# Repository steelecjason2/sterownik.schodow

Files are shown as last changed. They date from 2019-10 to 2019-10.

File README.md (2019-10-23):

16 stairs LED controller, and it's easy to extend by connecting just few wires to next TLC5940 PWM LED driver. 

parts not listed in schematics:

2x E18-D80NK Sensor Proximity 3-80cm,

2x microswitches, normal open.

SANPU 12VDC Waterproof LED Power Supply 12V DC 120W 10A IP67

Bluetooth HC-05

LED Strip 12V

PGM5516 photoresistor

2x potentiometer 10k multi-turn type 3/8''

https://www.youtube.com/watch?v=NjSVoOenioQ

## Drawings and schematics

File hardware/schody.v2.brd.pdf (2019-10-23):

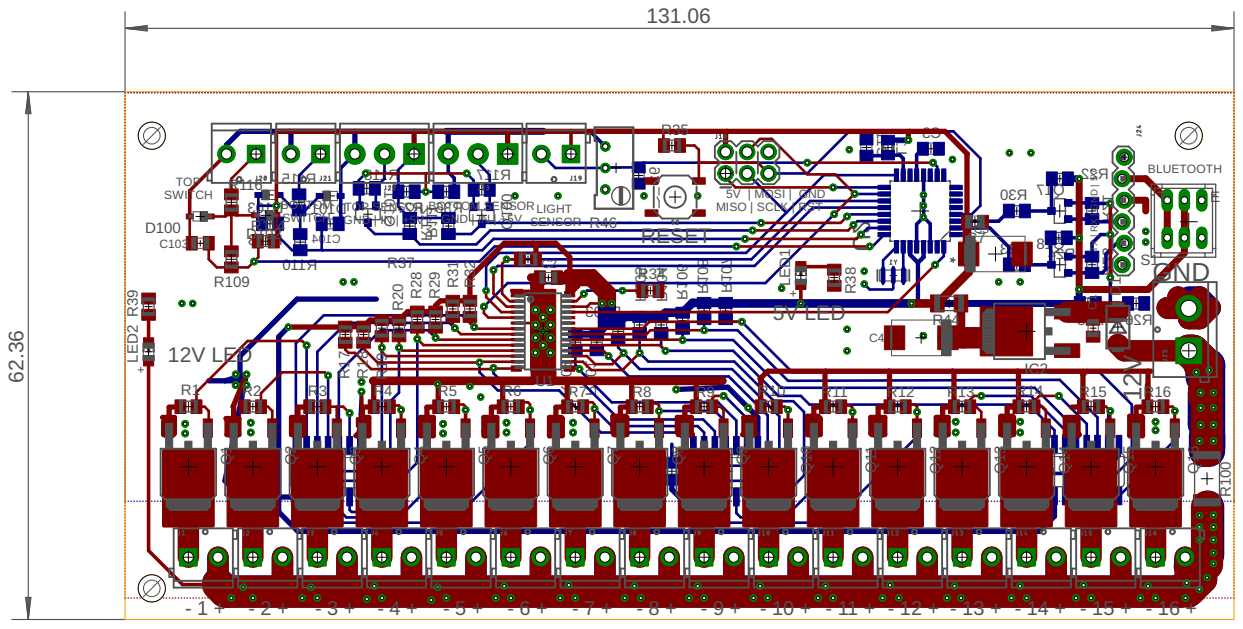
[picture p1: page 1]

TOP SENSOR GND | IN | +5V

5V | MOSI | GND MISO | SCLK | RST

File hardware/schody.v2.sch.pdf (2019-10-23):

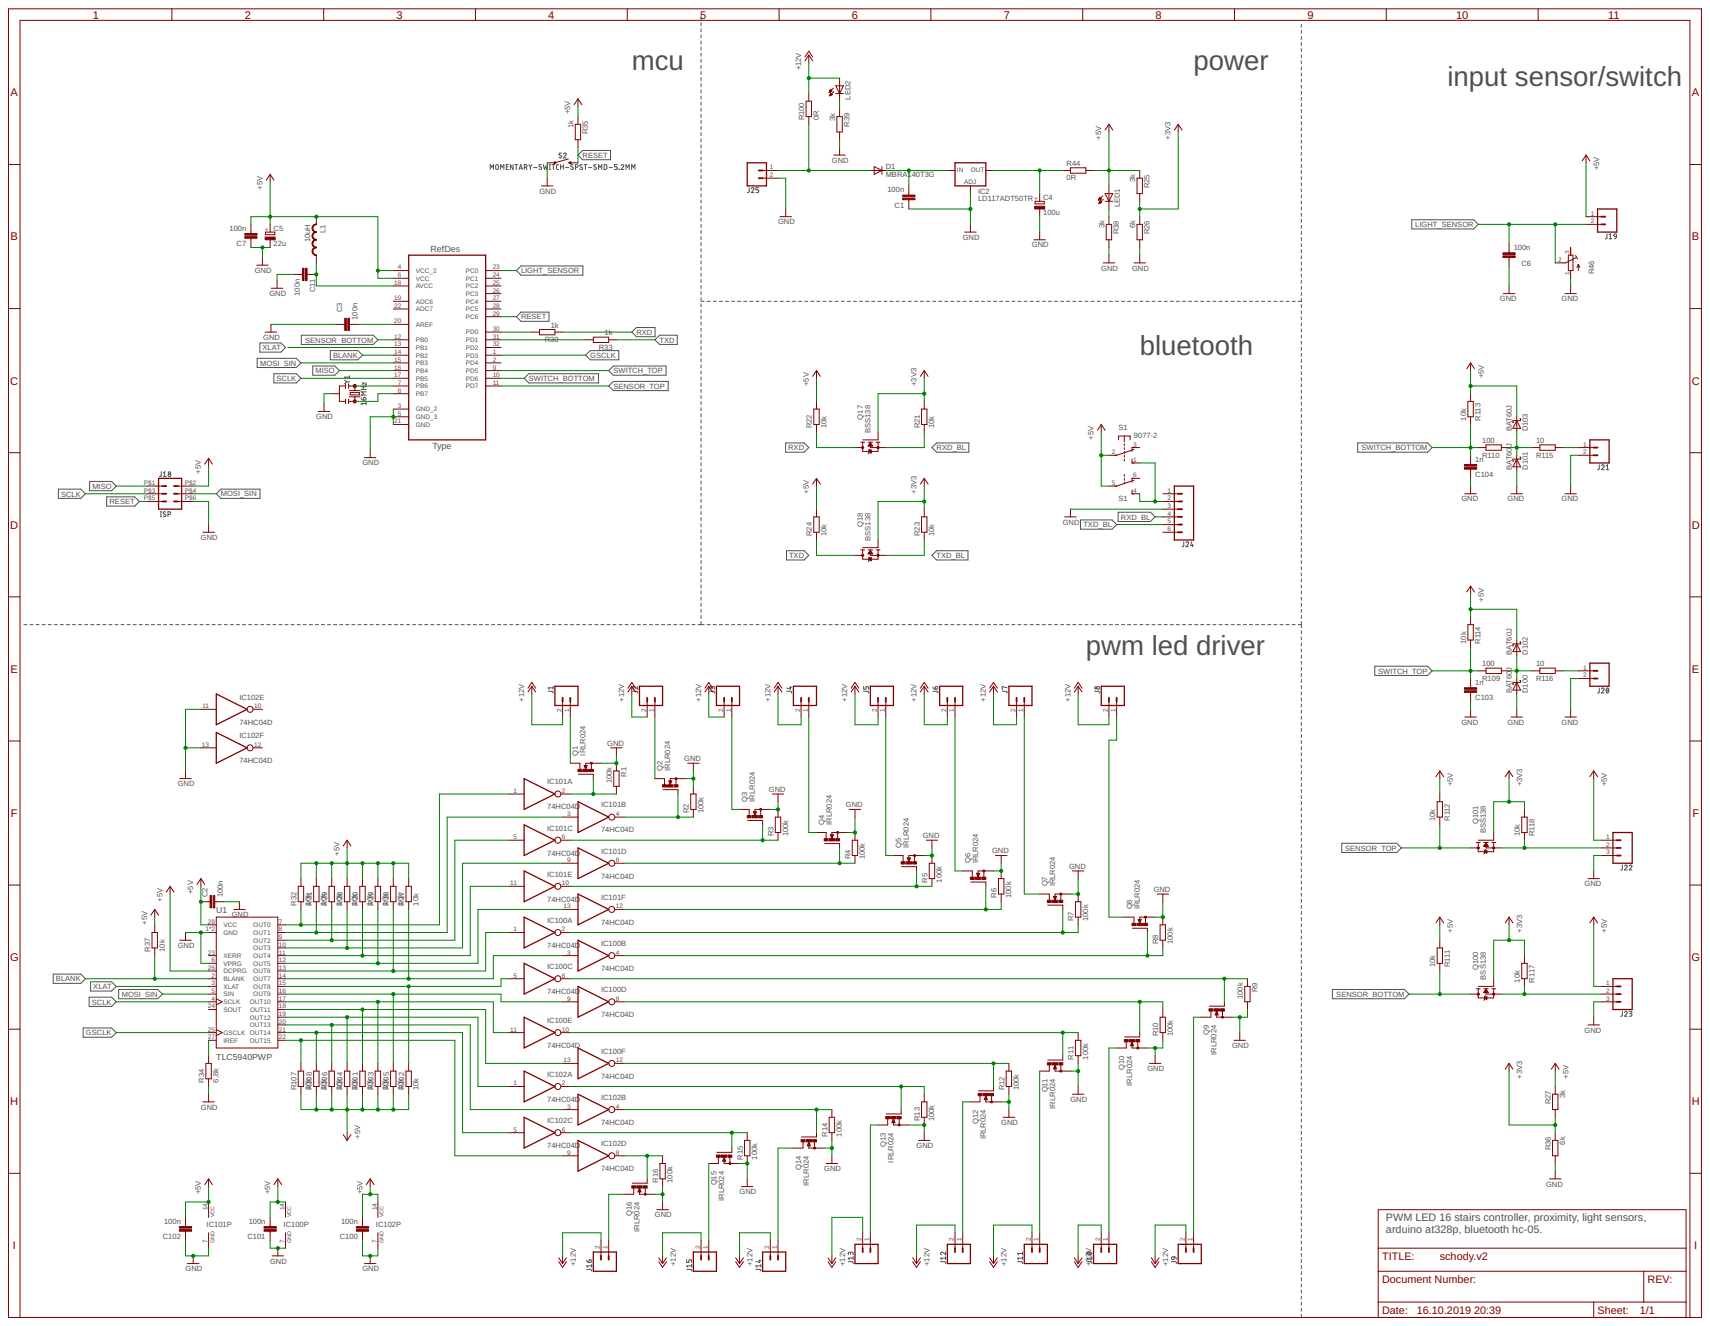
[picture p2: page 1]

PWM LED 16 stairs controller, proximity, light sensors, arduino at328p, bluetooth hc-05.

Document Number: | REV:

Date: 16.10.2019 20:39 | Sheet: 1/1

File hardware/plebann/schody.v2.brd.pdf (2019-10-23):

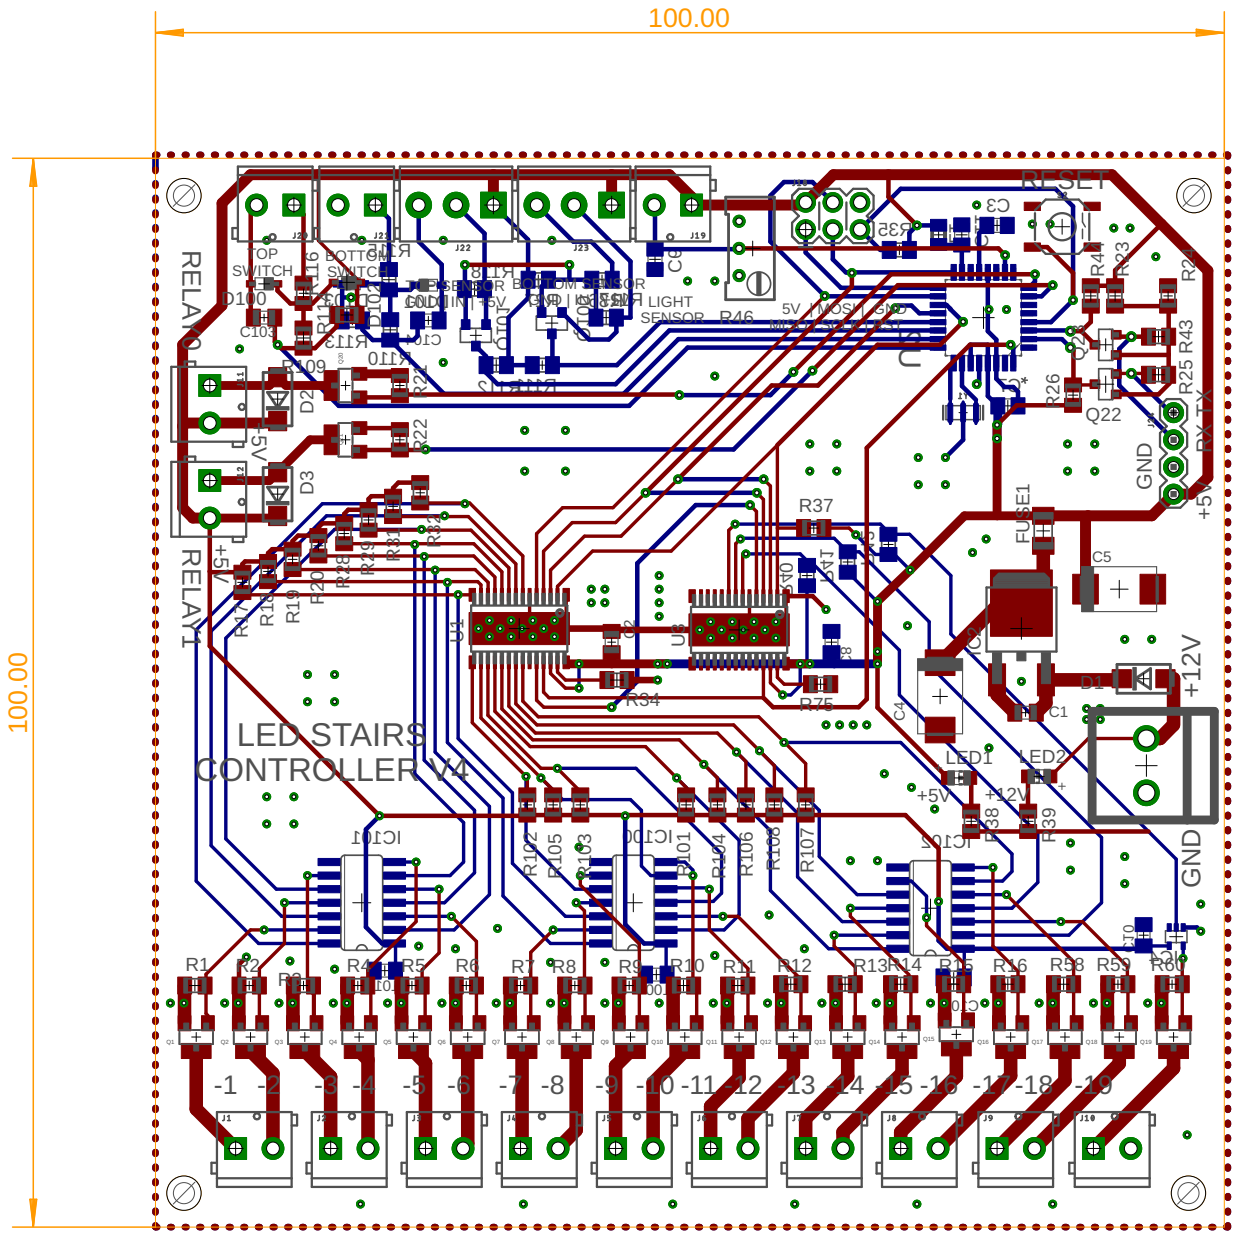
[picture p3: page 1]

BOTTOM SENSOR GND | IN | +5V

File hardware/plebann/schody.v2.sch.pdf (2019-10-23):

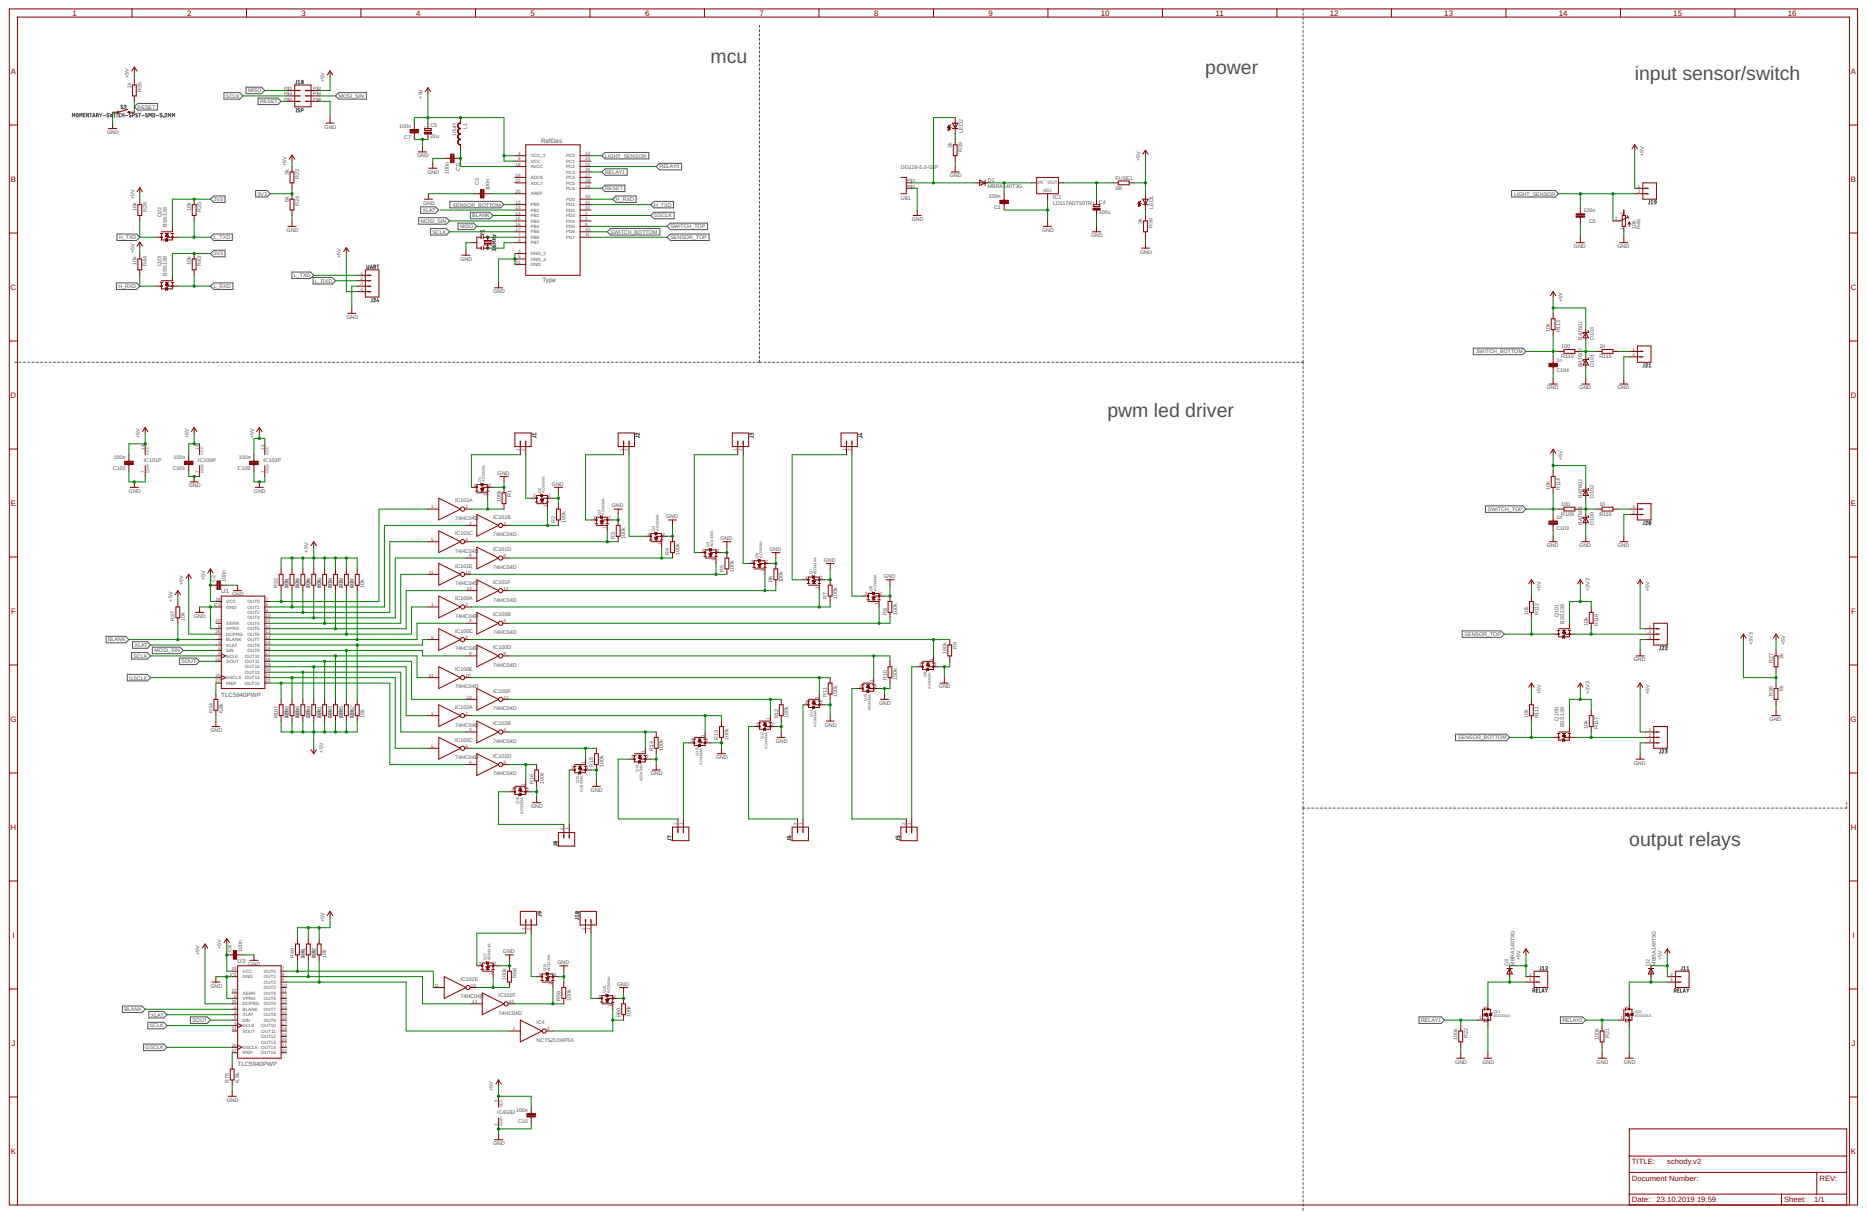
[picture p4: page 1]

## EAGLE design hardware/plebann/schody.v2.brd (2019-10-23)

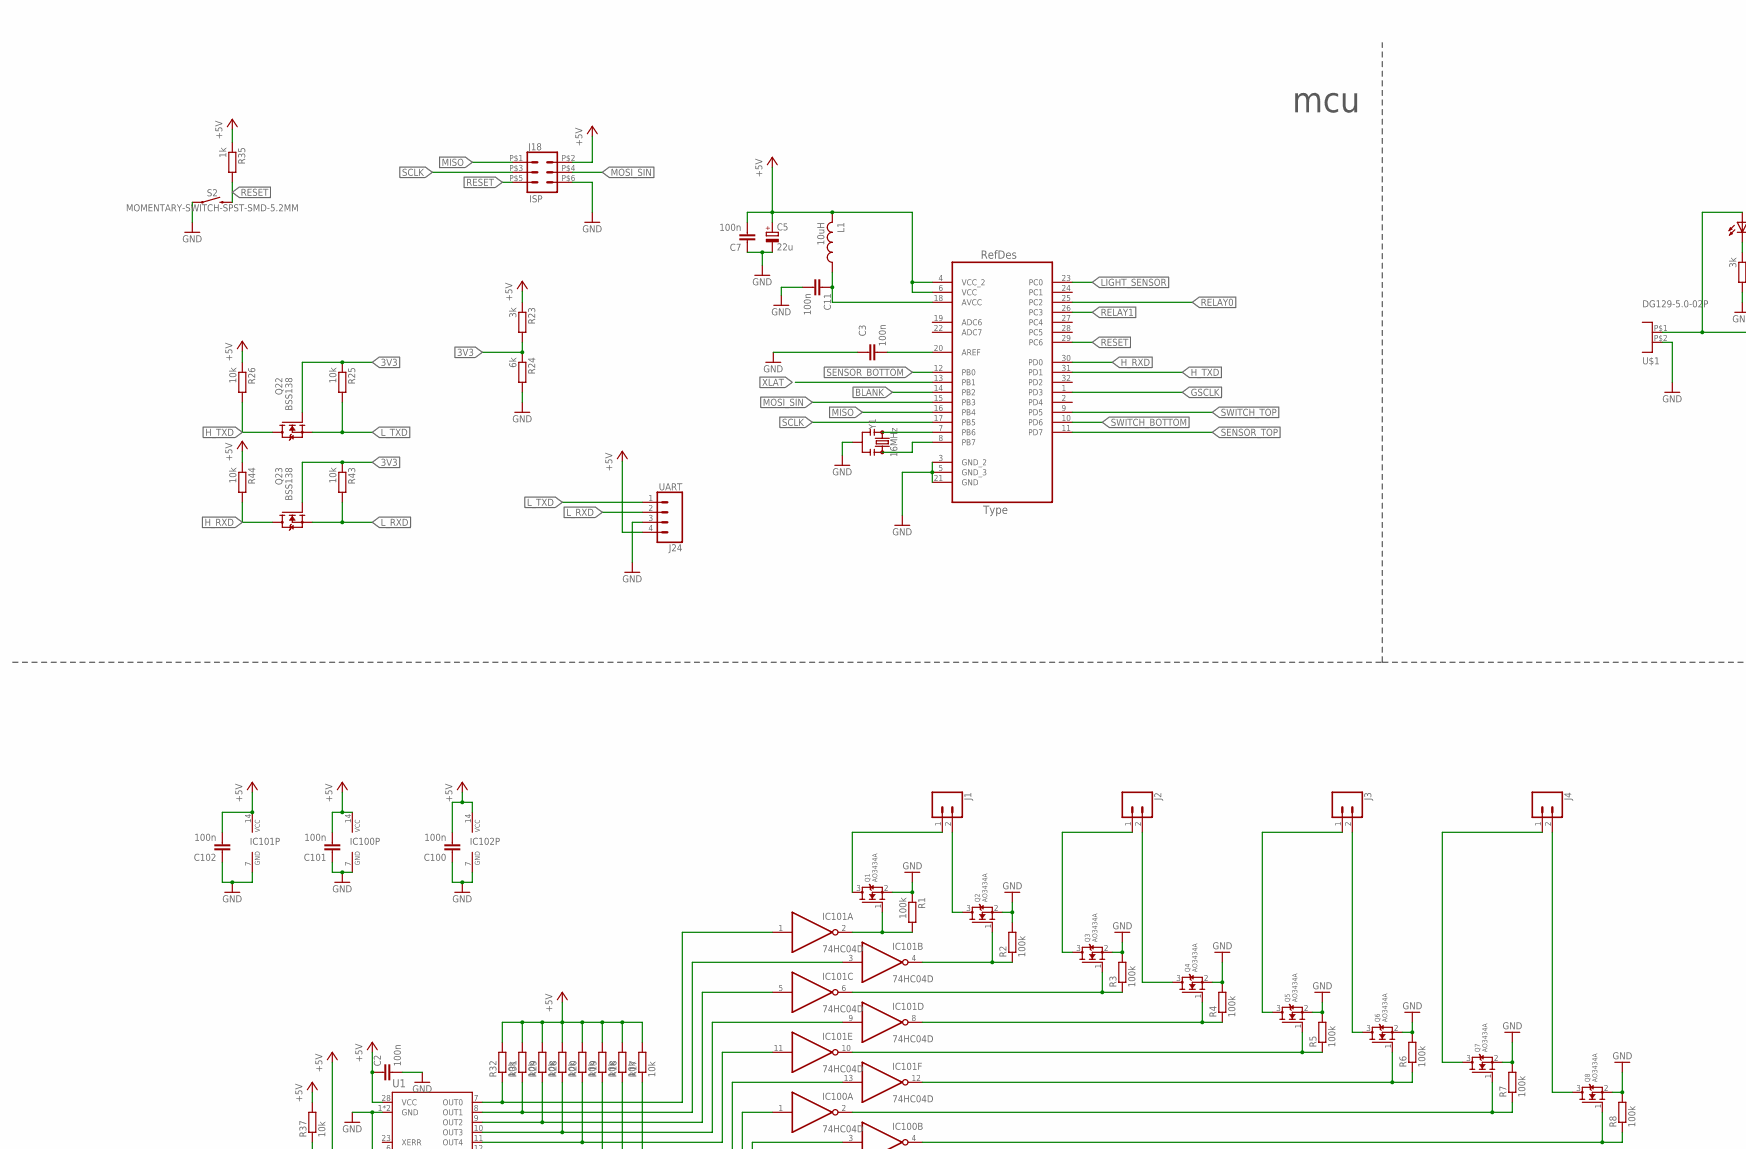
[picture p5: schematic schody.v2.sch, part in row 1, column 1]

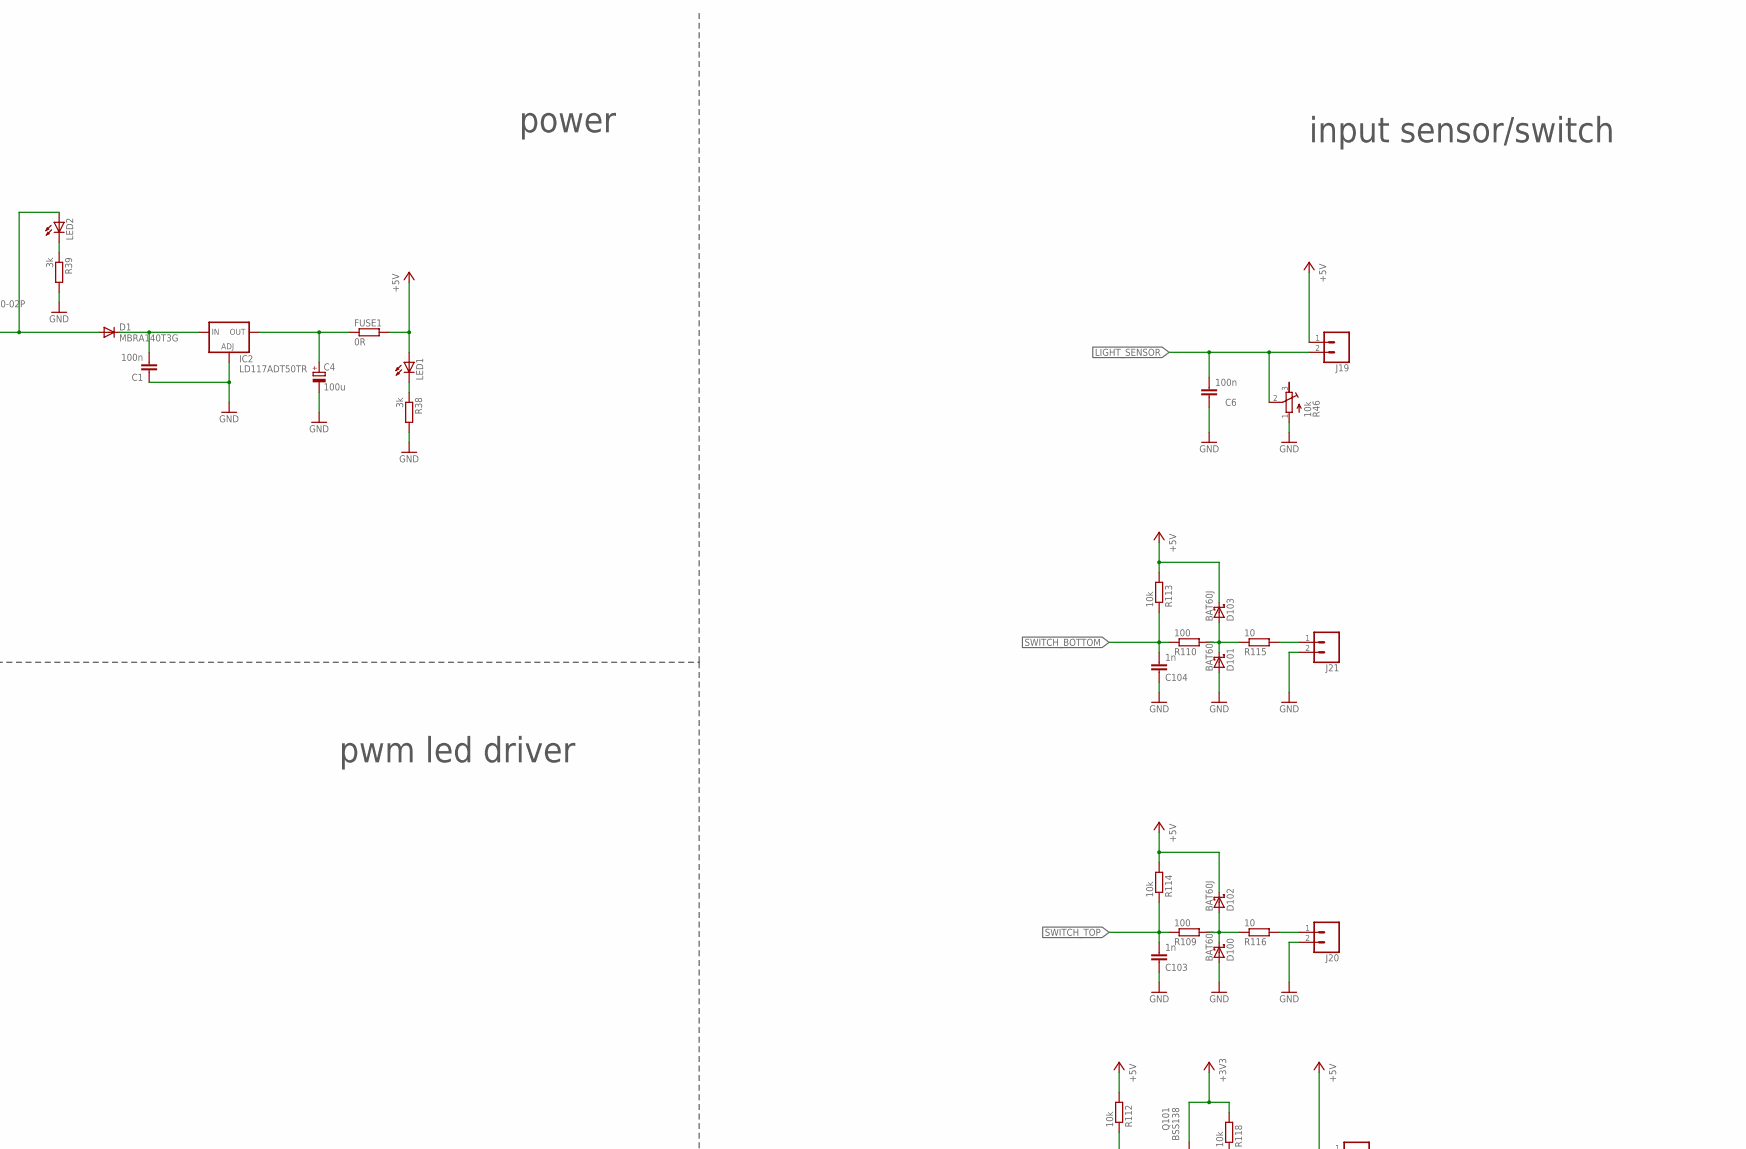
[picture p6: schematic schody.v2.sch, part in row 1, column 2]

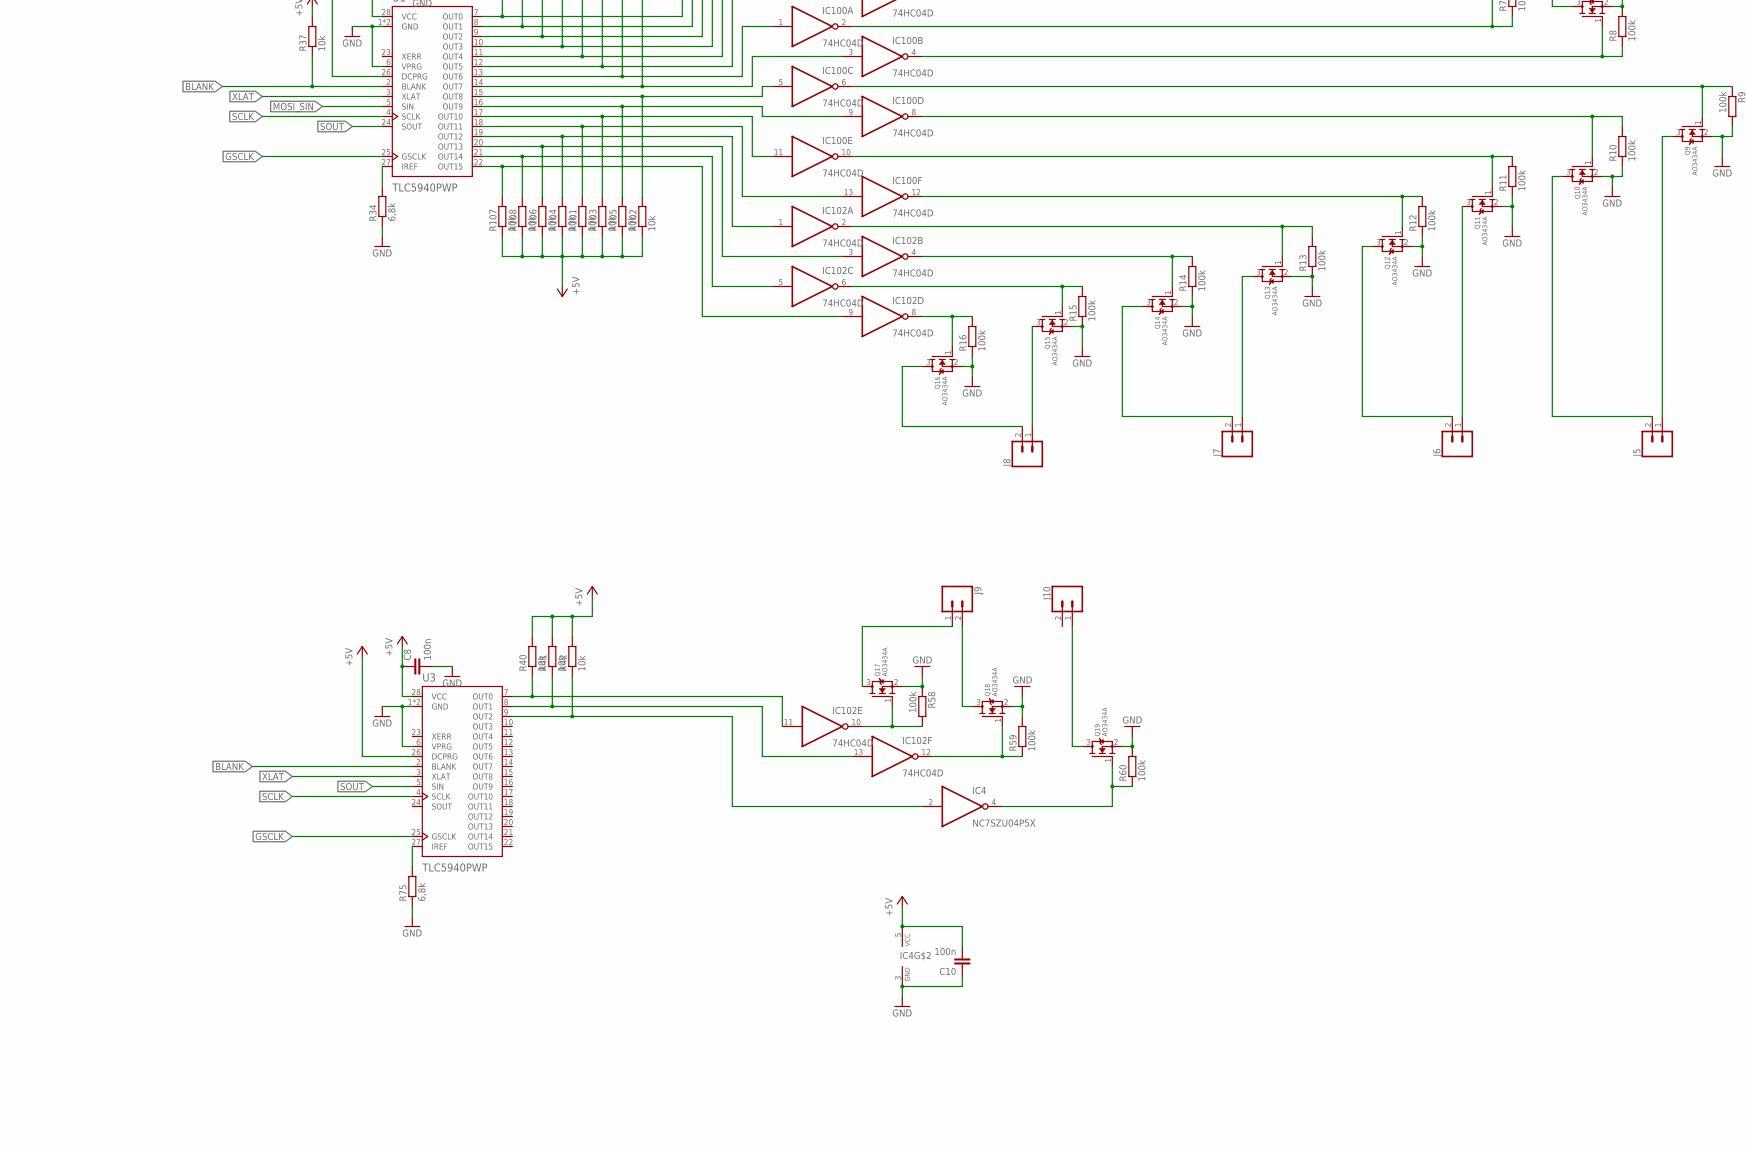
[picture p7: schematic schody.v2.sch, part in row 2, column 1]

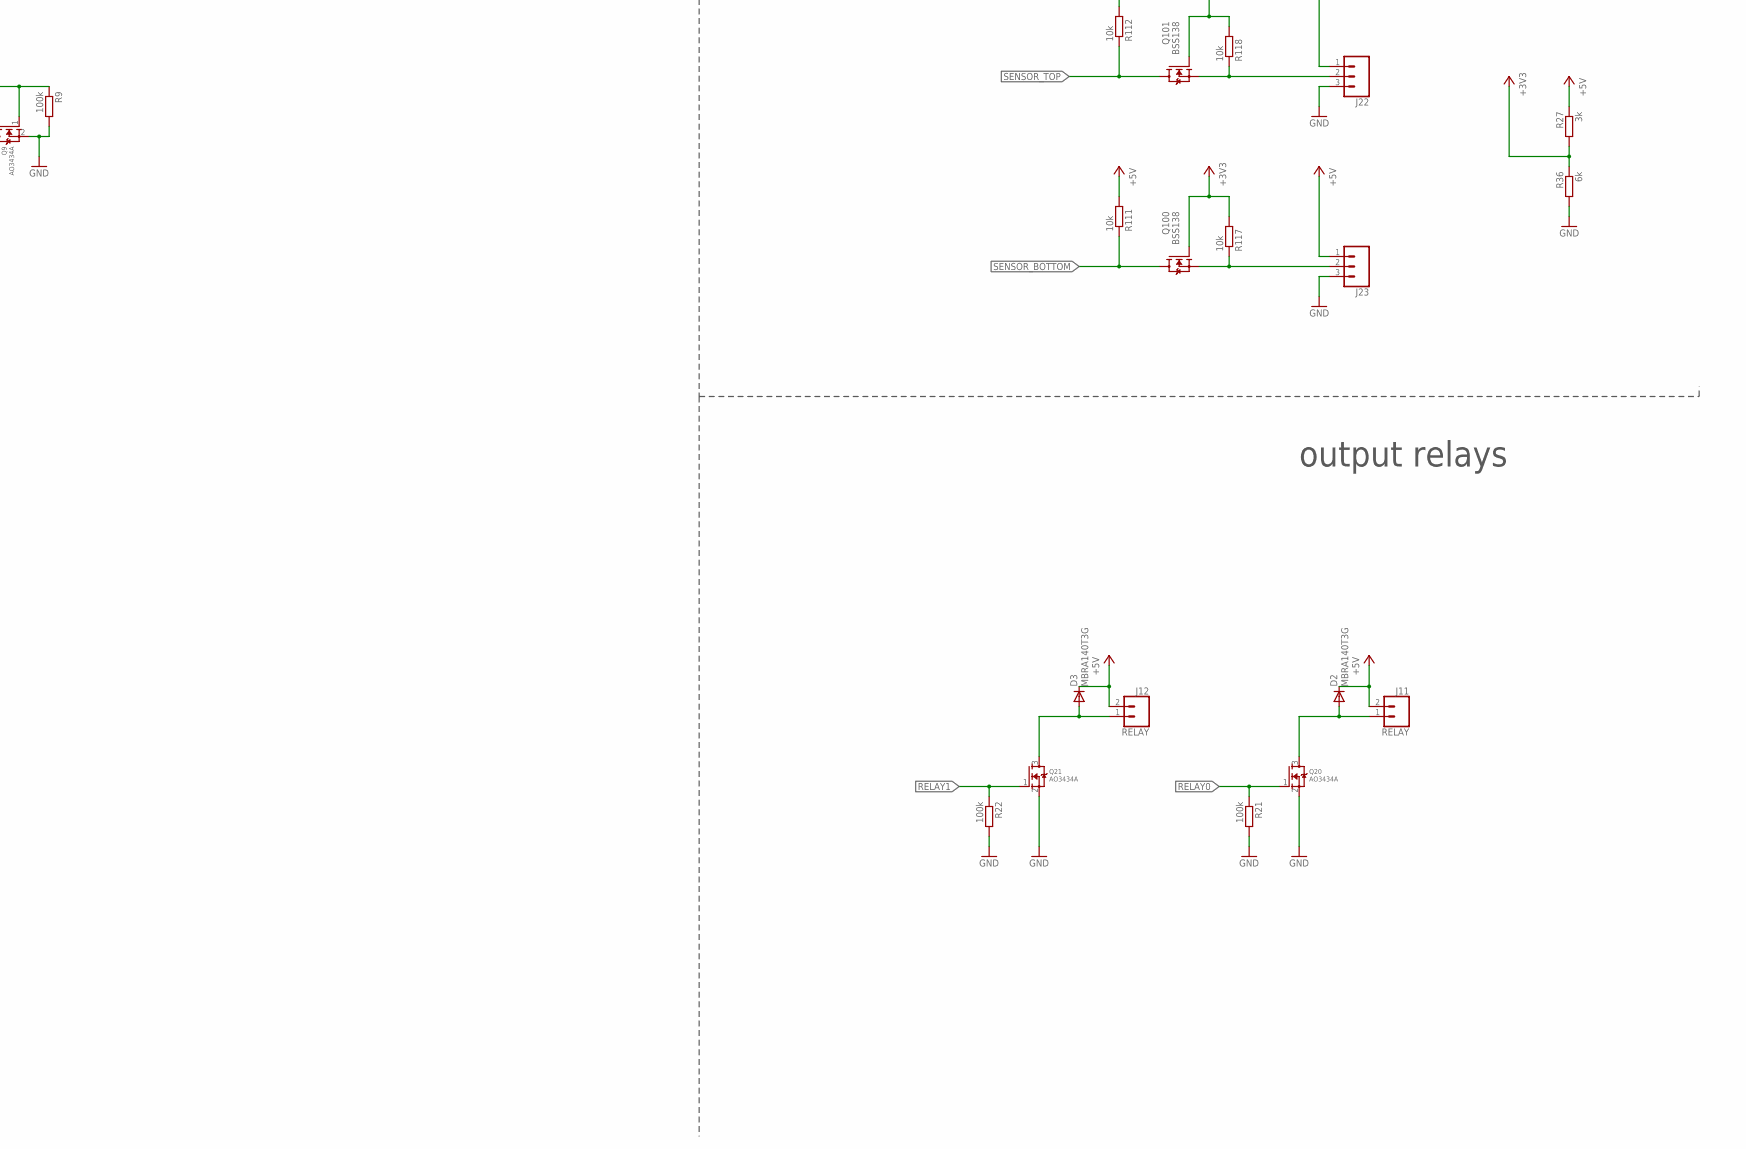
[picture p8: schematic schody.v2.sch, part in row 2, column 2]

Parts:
C1, C2, C8, C10, C100, C101, C102: 100n; C0805K
C3, C6, C7, C11: 100n; C0805
C4: 100u; SMC_D
C5: 22u; SMC_E
C103, C104: 1n; C0805K
D1, D2, D3: MBRA140T3G; DO214BA
D100, D101, D102, D103: BAT60J; SOD323_ST
FUSE1: 0R; M1206
IC2: LD117ADT50TR; DPACK
IC4: NC7SZU04P5X; SC70-5
IC100, IC101, IC102: 74HC04D; SO14
J1, J2, J3, J4, J5, J6, J7, J8, J9, J10, J19, J20, J21: CONN_023.5MM; SCREWTERMINAL-3.5MM-2
J11, J12: RELAY; SCREWTERMINAL-3.5MM-2
J18: ISP; 2X3_POGO
J22, J23: CONN_03SCREW; SCREWTERMINAL-3.5MM-3
J24: UART; 1X04
L1: 10uH; 0805
LED1, LED2: LEDCHIP-LED0805; CHIP-LED0805
Q1, Q2, Q3, Q4, Q5, Q6, Q7, Q8, Q9, Q10, Q11, Q12, Q13, Q14, Q15, Q16, Q17, Q18, Q19, Q20, Q21: AO3434A; SOT23-W
Q22, Q23, Q100, Q101: BSS138; SOT23
R1, R2, R3, R4, R5, R6, R7, R8, R9, R10, R11, R12, R13, R14, R15, R16, R21, R22, R58, R59, R60: 100k; M0805
R17, R18, R19, R20, R25, R26, R28, R29, R31, R32, R37, R40, R41, R42, R43, R44, R101, R102, R103, R104, R105, R106, R107, R108, R111, R112, R113, R114, R117, R118: 10k; M0805
R23, R27, R38, R39: 3k; M0805
R24, R36: 6k; M0805
R34, R75: 6,8k; M0805
R35: 1k; M0805
R46: 10k; RTRIM64W
R109, R110: 100; M0805
R115, R116: 10; M0805
S2: MOMENTARY-SWITCH-SPST-SMD-5.2MM; TACTILE_SWITCH_SMD_5.2MM
U1, U3: TLC5940PWP; HTSSOP28PWP
U2: ATMEGA328P-AU; QFP80P900X900X120-32N
U$1: DG129-5.0-02P
Y1: 16MHz; RESONATOR-SMD-3.2X1.3

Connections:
3V3: Q22.1 (G), Q23.1 (G), R23.2, R24.1, R25.1, R43.1
+3V33: Q100.1 (G), Q101.1 (G), R27.2, R36.1, R117.2, R118.2
+5V: C2.1, C5.+, C7.2, C8.1, C10.2, C100.2, C101.2, C102.2, D2.C, D3.C, D102.C, D103.C, FUSE1.2, IC4.5 (VCC), IC100.14 (VCC), IC101.14 (VCC), IC102.14 (VCC), J11.2, J12.2, J18.P$2 (2), J19.1, J22.1, J23.1, J24.4, L1.2, LED1.A, R17.2, R18.2, R19.2, R20.2, R23.1, R26.1, R27.1, R28.2, R29.2, R31.2, R32.2, R35.1, R37.2, R40.2, R41.2, R42.2, R44.1, R101.1, R102.1, R103.1, R104.1, R105.1, R106.1, R107.1, R108.1, R111.2, R112.2, R113.2, R114.2, U1.26 (DCPRG), U1.28 (VCC), U2.4 (VCC_2), U2.6 (VCC), U3.26 (DCPRG), U3.28 (VCC)
BLANK: R37.1, U1.2 (BLANK), U2.14 (PB2), U3.2 (BLANK)
GND: C1.1, C2.2, C3.1, C4.-, C5.-, C6.1, C7.1, C8.2, C10.1, C11.2, C100.1, C101.1, C102.1, C103.1, C104.1, D100.A, D101.A, IC2.1 (ADJ), IC4.3 (GND), IC100.7 (GND), IC101.7 (GND), IC102.7 (GND), J18.P$6 (6), J20.2, J21.2, J22.3, J23.3, J24.3, Q1.2 (S), Q2.2 (S), Q3.2 (S), Q4.2 (S), Q5.2 (S), Q6.2 (S), Q7.2 (S), Q8.2 (S), Q9.2 (S), Q10.2 (S), Q11.2 (S), Q12.2 (S), Q13.2 (S), Q14.2 (S), Q15.2 (S), Q16.2 (S), Q17.2 (S), Q18.2 (S), Q19.2 (S), Q20.2 (S), Q21.2 (S), R1.1, R2.2, R3.2, R4.2, R5.2, R6.2, R7.2, R8.2, R9.2, R10.1, R11.1, R12.1, R13.1, R14.1, R15.1, R16.1, R21.2, R22.2, R24.2, R34.1, R36.2, R38.2, R39.2, R46.1 (A), R58.1, R59.2, R60.2, R75.1, S2.1, U1.1 (GND), U1.6 (VPRG), U1.EXP (GND), U2.3 (GND_2), U2.5 (GND_3), U2.21 (GND), U3.1 (GND), U3.6 (VPRG), U3.EXP (GND), U$1.P$2, Y1.2
GSCLK: U1.25 (GSCLK), U2.1 (PD3), U3.25 (GSCLK)
H_RXD: Q23.3 (D), R44.2, U2.30 (PD0)
H_TXD: Q22.3 (D), R26.2, U2.31 (PD1)
LIGHT_SENSOR: C6.2, J19.2, R46.2 (S), U2.23 (PC0)
L_RXD: J24.2, Q23.2 (S), R43.2
L_TXD: J24.1, Q22.2 (S), R25.2
MISO: J18.P$1 (1), U2.16 (PB4)
MOSI_SIN: J18.P$4 (4), U1.5 (SIN), U2.15 (PB3)
unnamed: IC101.1 (I), R32.1, U1.7 (OUT0)
unnamed: IC101.3 (I), R31.1, U1.8 (OUT1)
unnamed: IC101.5 (I), R29.1, U1.9 (OUT2)
unnamed: IC101.9 (I), R28.1, U1.10 (OUT3)
unnamed: IC101.11 (I), R20.1, U1.11 (OUT4)
unnamed: IC101.13 (I), R19.1, U1.12 (OUT5)
unnamed: IC100.1 (I), R18.1, U1.13 (OUT6)
unnamed: IC100.3 (I), R17.1, U1.14 (OUT7)
unnamed: IC102.9 (I), R107.2, U1.22 (OUT15)
unnamed: IC101.2 (O), Q1.1 (G), R1.2
unnamed: IC102.3 (I), R106.2, U1.20 (OUT13)
unnamed: IC102.1 (I), R104.2, U1.19 (OUT12)
unnamed: IC100.13 (I), R101.2, U1.18 (OUT11)
unnamed: IC100.11 (I), R103.2, U1.17 (OUT10)
unnamed: IC100.9 (I), R105.2, U1.16 (OUT9)
unnamed: IC100.5 (I), R102.2, U1.15 (OUT8)
unnamed: IC102.5 (I), R108.2, U1.21 (OUT14)
unnamed: J4.2, Q8.3 (D)
unnamed: IC101.6 (O), Q3.1 (G), R3.1
unnamed: J2.2, Q4.3 (D)
unnamed: IC100.4 (O), Q8.1 (G), R8.1
unnamed: J2.1, Q3.3 (D)
unnamed: IC101.8 (O), Q4.1 (G), R4.1
unnamed: IC102.8 (O), Q16.1 (G), R16.2
unnamed: J8.2, Q16.3 (D)
unnamed: J1.1, Q1.3 (D)
unnamed: IC101.10 (O), Q5.1 (G), R5.1
unnamed: J3.1, Q5.3 (D)
unnamed: J9.2, Q18.3 (D)
unnamed: IC101.12 (O), Q6.1 (G), R6.1
unnamed: J5.2, Q10.3 (D)
unnamed: J3.2, Q6.3 (D)
unnamed: IC102.6 (O), Q15.1 (G), R15.2
unnamed: J1.2, Q2.3 (D)
unnamed: J6.1, Q11.3 (D)
unnamed: IC102.4 (O), Q14.1 (G), R14.2
unnamed: J7.2, Q14.3 (D)
unnamed: IC100.8 (O), Q10.1 (G), R10.2
unnamed: IC102.2 (O), Q13.1 (G), R13.2
unnamed: IC100.6 (O), Q9.1 (G), R9.1
unnamed: J7.1, Q13.3 (D)
unnamed: J20.1, R116.2
unnamed: IC100.12 (O), Q12.1 (G), R12.2
unnamed: J6.2, Q12.3 (D)
unnamed: J5.1, Q9.3 (D)
unnamed: IC100.10 (O), Q11.1 (G), R11.2
unnamed: J8.1, Q15.3 (D)
unnamed: J21.1, R115.2
unnamed: C1.2, D1.C, IC2.3 (IN)
unnamed: U2.7 (PB6), Y1.1
unnamed: U2.8 (PB7), Y1.3
unnamed: R34.2, U1.27 (IREF)
unnamed: LED1.C, R38.1
unnamed: D101.C, D103.A, R110.2, R115.1
unnamed: LED2.C, R39.1
unnamed: D100.C, D102.A, R109.2, R116.1
unnamed: IC102.13 (I), R41.1, U3.8 (OUT1)
unnamed: D2.A, J11.1, Q20.3 (D)
unnamed: IC4.2 (I), R42.1, U3.9 (OUT2)
unnamed: J22.2, Q101.2 (S), R118.1
unnamed: J23.2, Q100.2 (S), R117.1
unnamed: C11.1, L1.1, U2.18 (AVCC)
unnamed: C4.+, FUSE1.1, IC2.4 (OUT)
unnamed: C3.2, U2.20 (AREF)
unnamed: IC102.11 (I), R40.1, U3.7 (OUT0)
unnamed: IC101.4 (O), Q2.1 (G), R2.1
unnamed: IC100.2 (O), Q7.1 (G), R7.1
unnamed: D1.A, LED2.A, U$1.P$1
unnamed: J4.1, Q7.3 (D)
unnamed: D3.A, J12.1, Q21.3 (D)
unnamed: IC4.4 (O), Q19.1 (G), R60.1
unnamed: R75.2, U3.27 (IREF)
unnamed: IC102.10 (O), Q17.1 (G), R58.2
unnamed: IC102.12 (O), Q18.1 (G), R59.1
unnamed: J10.1, Q19.3 (D)
unnamed: J9.1, Q17.3 (D)
RELAY0: Q20.1 (G), R21.1, U2.25 (PC2)
RELAY1: Q21.1 (G), R22.1, U2.26 (PC3)
RESET: J18.P$5 (5), R35.2, S2.3 (2), U2.29 (PC6)
SCLK: J18.P$3 (3), U1.4 (SCLK), U2.17 (PB5), U3.4 (SCLK)
SENSOR_BOTTOM: Q100.3 (D), R111.1, U2.12 (PB0)
SENSOR_TOP: Q101.3 (D), R112.1, U2.11 (PD7)
SOUT: U1.24 (SOUT), U3.5 (SIN)
SWITCH_BOTTOM: C104.2, R110.1, R113.1, U2.10 (PD6)
SWITCH_TOP: C103.2, R109.1, R114.1, U2.9 (PD5)
XLAT: U1.3 (XLAT), U2.13 (PB1), U3.3 (XLAT)

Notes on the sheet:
mcu
power
input sensor/switch
pwm led driver
output relays

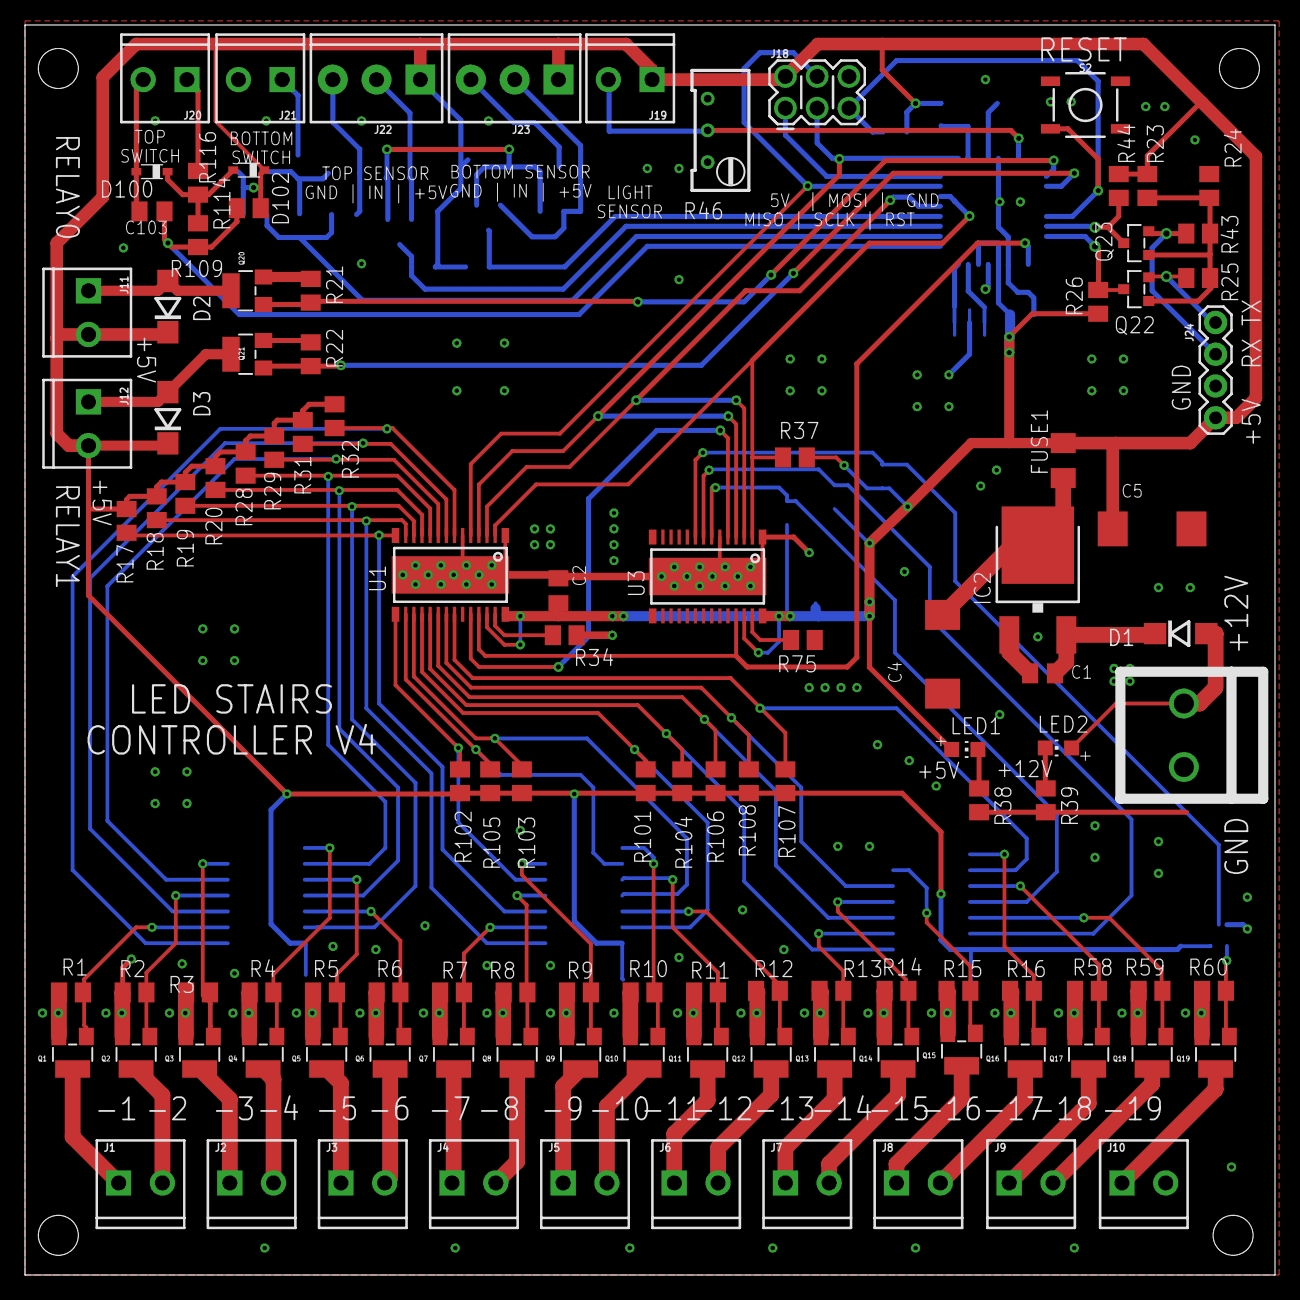
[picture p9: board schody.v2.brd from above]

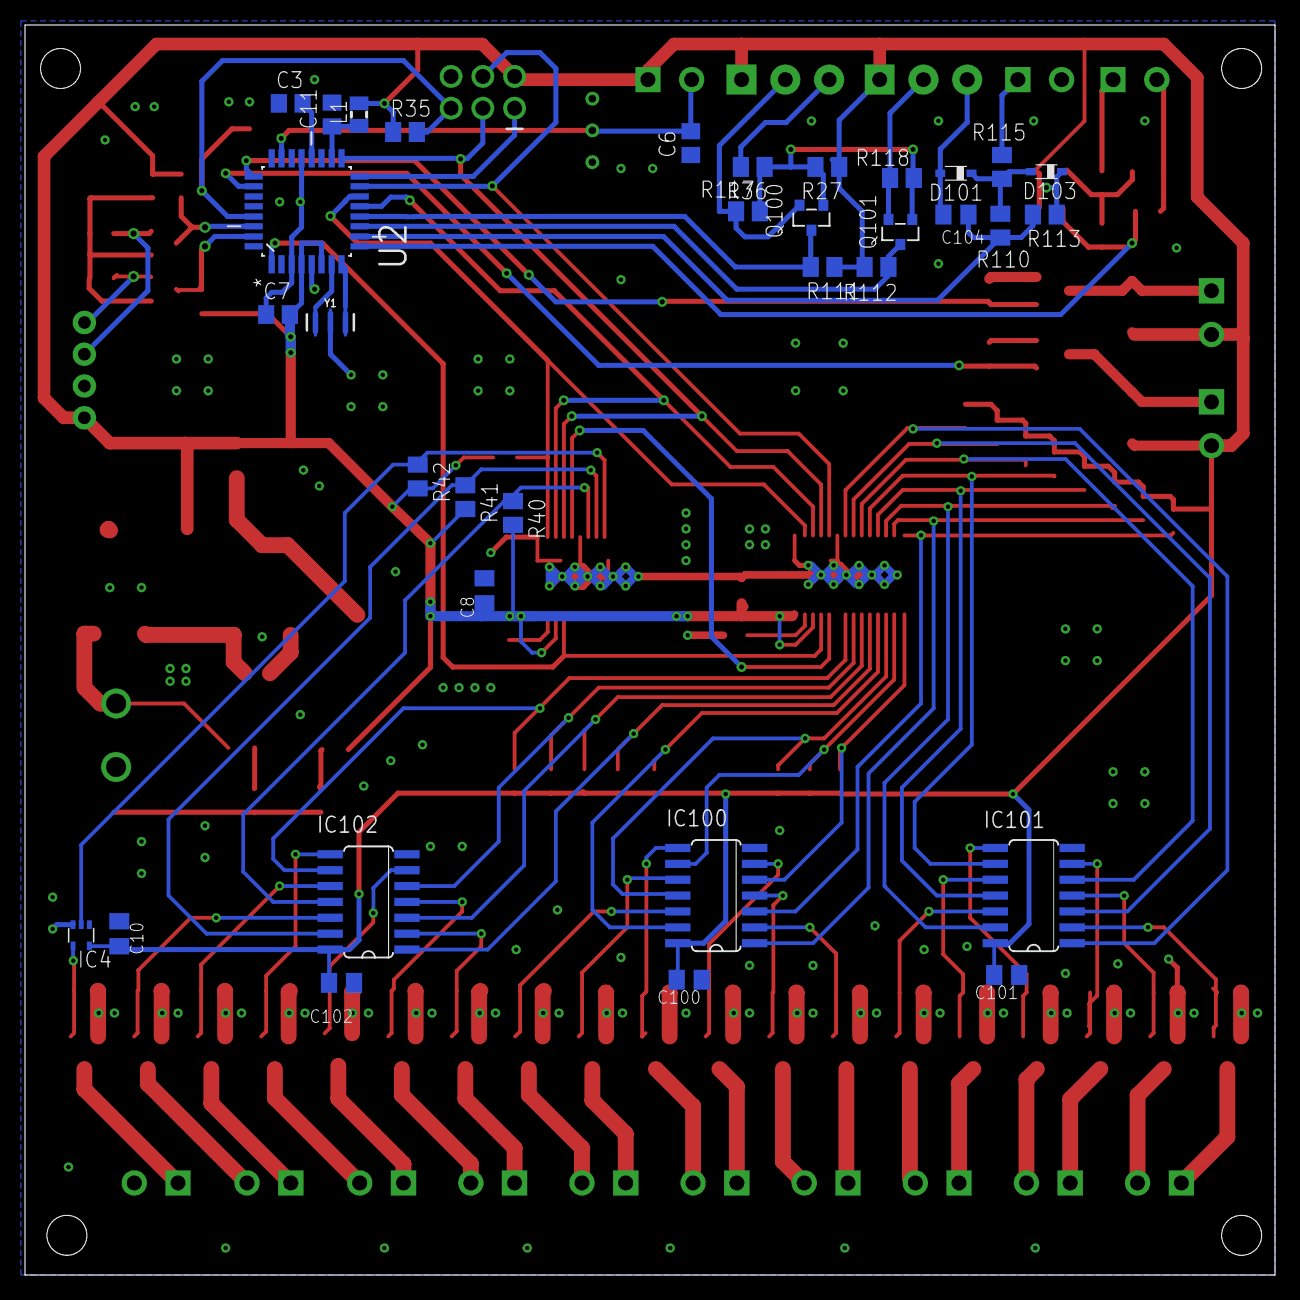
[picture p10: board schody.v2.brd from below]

Board: 2 copper layers, 100.0 x 100.0 mm, 146 parts (34 on the bottom side), 99 nets.

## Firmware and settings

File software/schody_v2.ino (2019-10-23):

#include <Tlc5940.h>
#include "ClickButton.h"
#include <EEPROM.h>

#define sensorPull LOW                                // HIGH for PIR sensor
#define baudrate 115200                               //  bluetooth module or diag. console

const int downButtonPin = 6;
const int upButtonPin = 5;
const int downSensorPin = 7;
const int upSensorPin = 8;
const int lightSensor = A1;
const int adjustmentPin = 12;
const int sensorPin0 = A0;


const int buttons = 4;                                // Nr. of buttons in the array
  ClickButton button[4] = {
  ClickButton (downButtonPin, LOW),
  ClickButton (upButtonPin, LOW),
  ClickButton (downSensorPin, sensorPull),        
  ClickButton (upSensorPin, sensorPull),         
};

int LEDfunction[buttons]  = { 0, 0, 0, 0 };

const int downButton = 0;
const int upButton = 1;
const int downSensor = 2;
const int upSensor = 3;

const int modeOff = 0;
const int modeBrighteningFromBottom = 1;
const int modeDimmingFromBottom = 2;
const int modeBrighteningFromTop = 3;
const int modeDimmingFromTop = 4;
const int modeBrighteningAll = 5;
const int modeDimmingAll = 6;
const int modeOn = 7;
const int modePartyBFB = 8;
const int modePartyDFB = 9;
const int modePartyBFT = 10;
const int modePartyDFT = 11;
const int modePartyNukeIn = 12;
const int modePartyNukeOut = 13;
const int modePartyRandOn = 14;
const int modePartyRandOff = 15;
const int modeBrighteningStandby = 16;
const int modeBrighteningFromBottomAlt = 17;
const int modeDimmingFromBottomAlt = 18;
const int modeBrighteningFromTopAlt = 19;
const int modeDimmingFromTopAlt = 20;
const int modePartyLarsonScannerR = 22;
const int modePartyLarsonScannerL = 23;
const int modePartyWaveUp = 24;
const int modePartyWaveDown = 25;
const int modePartySparkle = 26;
const int modeConfirm = 27;
const int modeStandby = 28;
const int modeWait = 29;

const int ledCount = 16;                              //nr. of led strips
int outs[ledCount]; 
int outState[ledCount];

int brightness = 1024;
int delayTime = 7;                                    // main loop delay
int prevValue = -1;                                   //for random number generator
int dimmingStep = 12;
int dimmingAltStep = 255;
int dimmingStepForAll = 8;
int brighteningStep = 96;
int brighteningAltStep = 100;
int brighteningStepForAll = 24;
int partyStep = 256;
int partyloopRand = 1;                                //must be 1 
int partyloopRandMax = 2;                             //number of randomOn and randomOff loops in partymode
int partyloopBD = 1;                                  //must be 1
int partyloopBDMax = 3;                               //number of brightening and dimming loops in partymode
int partyloopScanner = 1;                             //must be 1
int partyloopScannerMax = 4;                          //number of larsonScanner loops in partymode
int partyWaveLength = 4;                              //must be 1
int partyloopWave = 1;                                //must be 1
int partyloopWaveMax = 1024;                          //number of wave loops in partymode
int partyloopNuke = 1;                                //must be 1
int partyloopNukeMax = 2;                             //number of nuke loops in partymode
int partySparkleFreq = 8;
int partyloopSparkle = 1;   
int partyloopSparkleMax = 1024;                       //number of nuke loops in partymode
int standby = 4;                                      //brightness value for standby mode
int mode = modeOff;
int revolutionSpeed = 0;                              //counter of party loop
bool alternative;                                     //alternative mode for brightening and dimming mode
bool standbyActive;                                   //for standby mode
char cmd[50];                                         // command to store from serial port
int cmdIndex;
int mark = 1;                                         //for wave mode, up and down
bool partyTest;                                       //for testing party modes, no loop, just one party mode
bool stateLight;                                      // for light sensor, 0 is dark state
int lightThreshold = 700;                             // for hysteresis of light sensor
int darkThreshold  = 300;                             // for hysteresis of light sensor
int nextMode;

int sensorState[] = {0,0};                            // for single trigger sensors status change
int lastSensorState[] = {0,0};                        // for single trigger sensors status change


unsigned long timeNow = 0;
unsigned long timePrevSensor = 0;
unsigned long timeDiffSensor = 1000;                  // period for light status check
unsigned long timePrevMode = 0;
unsigned long waitDuration = 3000;                    // time between brightening and dimming





void setup()
{

  delay(500);                                         // wait for bluetooth module to start
  cmdIndex = 0;
  Serial.begin(baudrate);

  mode = 0;
  alternative = false;
  standbyActive = false;
  partyTest = false;


  if(!loadConfig()){                                  //loading settings from eeprom memory, and checking if there is any configuration
    Serial.println("configuration not loaded!");
    saveConfig();                                     // overwrite with the default settings
  }
  
  if (standbyActive == 1) mode = modeBrighteningStandby;

  randomSeed(analogRead(sensorPin0));                 //analog input 0 pin, as the seed for random numbers generator 
  pinMode(lightSensor, INPUT);                        // light sensor as input A1 pin
  pinMode(adjustmentPin, INPUT);                      // light sensor as input 12 pin

  Tlc.init();

    button[0].debounceTime   = 20;                    // Debounce timer in ms
    button[0].multiclickTime = 600;                   // Time limit for multi clicks
    button[0].longClickTime  = 1100;                  // Time until long clicks register
    button[1].debounceTime   = 20;                    // Debounce timer in ms
    button[1].multiclickTime = 600;                   // Time limit for multi clicks
    button[1].longClickTime  = 1100;                  // Time until long clicks register
    button[2].debounceTime   = 20;                    // Debounce timer in ms
    button[2].multiclickTime = 50;                    // Time limit for multi clicks
    button[2].longClickTime  = 100000;                // Time until long clicks register
    button[3].debounceTime   = 20;                    // Debounce timer in ms
    button[3].multiclickTime = 50;                    // Time limit for multi clicks
    button[3].longClickTime  = 100000;                // Time until long clicks register
   
    int input = analogRead(lightSensor);              //check for light state
    if (input < darkThreshold) stateLight = false;
    else stateLight = true;

    for (int i = 0; i < ledCount; i++) {
      outs[i] = ledCount - i - 1;                     //outputs for led strips, inverted, first on top, last on bottom
      outState[i] = 0;
    } 

   updateLed();

}

void loop()
{
  timeNow = millis();
  
    for (int i = 0; i < buttons; i++) {
      button[i].Update();                             // Update state of all buttons
      if (button[i].clicks != 0) {                    // Save click codes in LEDfunction, as clicks counts are reset at next Update()
        LEDfunction[i] = button[i].clicks; 
      }
      
      if(i < 2) {
        
        if (button[i].clicks == 1) {                   // for stairs brightening or dimming
          modeSet(i);
        }
      
        if (button[i].clicks == 2) {                    // standby mode
          standbyActive=!standbyActive;
          modeSetStandby();
        }
        if (button[i].clicks == 3) {                    // confirm of change for stairs brightening or dimming
          alternative=!alternative;
          mode = modeConfirm;
        }
        if (button[i].clicks == 5) {                    // party mode
          standbyActive = 0;
          modeSetParty();
        }
        if(LEDfunction[i] == -1) {                      // brightening all or dimming all with constant mode
        modeSetAll();
        LEDfunction[i] = 0;
        }
      }
    
    else {
          lightSensorRead();
          sensorState[i-2] = button[i].depressed;
          if ((sensorState[i-2] != lastSensorState[i-2]) && (sensorState[i-2] == (!sensorPull))) {     // triggering lights only when change of state and sensors state active
            if (!stateLight) modeSet(i);
            else lightSensorPrint(i);     
          }
          lastSensorState[i-2] = sensorState[i-2];
    }   
} 
  
  if (timeNow - timePrevSensor >= timeDiffSensor || timeNow < timePrevSensor) {
    timePrevSensor = timeNow;
    modeSetStandby();
  }

  updateCircuitState(); 
  updateLed();
  readFromSerial();   
  delay(delayTime);
}



void updateLed() {
   for (int diode = 0; diode < ledCount;diode++) {
     Tlc.set(outs[diode], outState[diode]);
    }
    Tlc.update();
}


void updateCircuitState() {
  switch (mode) {
  case modeOff:
    off(); break;
  case modeBrighteningFromBottom:
    brighteningFromBottom(); break;
  case modeDimmingFromBottom:
    dimmingFromBottom(); break;
  case modeBrighteningFromTop:
    brighteningFromTop(); break;
  case modeDimmingFromTop:
    dimmingFromTop(); break;
  case modeBrighteningAll:
    brighteningAll(); break;
  case modeDimmingAll:
    dimmingAll(); break;
  case modePartyBFB:
    partyBFB(); break;
  case modePartyDFB:
    partyDFB(); break;
  case modePartyBFT:
    partyBFT(); break;
  case modePartyDFT:
    partyDFT(); break;
  case modePartyNukeIn:
    partyNukeIn(); break;
  case modePartyNukeOut:
    partyNukeOut(); break;
  case modePartySparkle:
    partySparkle(); break;
  case modePartyRandOn:
    partyRandOn(); break;
  case modePartyRandOff:
    partyRandOff(); break;
  case modeBrighteningFromBottomAlt:
    brighteningFromBottomAlt(); break;
  case modeDimmingFromBottomAlt:
    dimmingFromBottomAlt(); break;
  case modeBrighteningFromTopAlt:
    brighteningFromTopAlt(); break;
  case modeDimmingFromTopAlt:
   dimmingFromTopAlt(); break;
  case modePartyLarsonScannerR:
    partyLarsonScannerR();break;
  case modePartyLarsonScannerL:
    partyLarsonScannerL(); break;
  case modePartyWaveUp:
    partyWaveUp(); break;
  case modePartyWaveDown:
    partyWaveDown(); break;
  case modeConfirm:
    confirm(); break;
  case modeBrighteningStandby:
      if (standbyActive && stateLight == 0) {
        brighteningStandby(); 
      }
      else {
        mode = modeOff;
      }
  break;
  case modeWait:
    waitForNextMode(); break;
  }
}



void waitForNextMode(){
  if (timeNow - timePrevMode >= waitDuration || timeNow < timePrevMode) {
    mode = nextMode;
  }
}

void postponeNextMode(int _nextMode) {
  mode = modeWait;
  timePrevMode = timeNow;
  nextMode = _nextMode;
}


void lightSensorRead() {
   //Input Hysteresis for fotoresistor light value
        int input = analogRead(lightSensor);

          if (stateLight) {
            if (input < darkThreshold)
            stateLight = false;
          }
          else  {
            if (input > lightThreshold) 
            stateLight = true;
          }          
}

void  off()  {                                         //turn all LEDs off
  
  bool changed = false;
  for (int diode = 0; diode < ledCount; diode++)
    if (outState[diode] > 0) {
      outState[diode] = 0;
      changed |= true;
    }
  return changed;
}
    


void confirm() {                                      //turn on for a moment last and first LED, to confirm the change alternative mode 
   bool changed = false;
   bool on = false;
     for (int diode = 1; diode < ledCount-1; diode++)
     if (outState[diode] > 0) on = true;
      if (on) {
        for (int diode = 0; diode < ledCount; diode++) {
        if (outState[diode] > 0) outState[diode] = 0;
        }
      changed = true;
      }
   
      if ((outState[0] < brightness) || (outState[ledCount-1] < brightness)) {
       int newState = outState[0];
      newState = newState + dimmingStep;
      if (newState > brightness) 
      newState = brightness;
      outState[0] = newState;
      outState[ledCount-1] = newState;
      changed = true;
      }
     else {
      for (int diode = 0; diode<ledCount;diode++) outState[diode] = 0;
     }
    
   if (!changed) 
    mode =  modeBrighteningStandby;    
}


void modeSet(int button) {

  lightSensorPrint(button);

  if (mode == modeOff || mode == modeStandby || mode == modeDimmingFromBottomAlt || mode == modeDimmingFromBottom || mode == modeDimmingFromTopAlt || mode == modeDimmingFromTop || 
      mode == modeBrighteningFromBottomAlt || mode == modeBrighteningFromBottom || mode == modeBrighteningFromTopAlt || mode == modeBrighteningFromTop) {    
        
    if (button == downButton) {
      if (alternative) mode = modeBrighteningFromBottomAlt;
      else mode = modeBrighteningFromBottom;
      }

    if (button == upButton) {
      if (alternative) mode = modeBrighteningFromTopAlt;
      else mode = modeBrighteningFromTop;
      }
  }
  // sensor is not triggering at dimming from top cycle, when person is passing last sensor. 
    if ((button == downSensor) && (mode == modeOff || mode == modeStandby ||            
        mode == modeBrighteningFromBottomAlt || mode == modeBrighteningFromBottom || mode == modeDimmingFromBottom || mode == modeDimmingFromBottomAlt)) {
      if (alternative) mode = modeBrighteningFromBottomAlt;
      else mode = modeBrighteningFromBottom;
      }
  // sensor is not triggering at dimming from bottom cycle, when person is passing last sensor.
    if ((button == upSensor) && (mode == modeOff || mode == modeStandby ||              
        mode == modeBrighteningFromTopAlt || mode == modeBrighteningFromTop || mode == modeDimmingFromTop || mode == modeDimmingFromTopAlt)) {
      if (alternative) mode = modeBrighteningFromTopAlt;
      else mode = modeBrighteningFromTop;
      }
}

void modeSetAll() {

    if (mode == modeOff || mode == modeStandby || mode == modeDimmingFromTop || mode == modeDimmingFromBottom || mode == modeDimmingFromTopAlt || mode == modeDimmingFromBottomAlt)
      {
        mode = modeBrighteningAll;
        Serial.println("All On");
      }
      
    if (mode == modeOn || mode == modeBrighteningFromTop || mode == modeBrighteningFromBottom || mode == modeBrighteningFromTopAlt || mode == modeBrighteningFromBottomAlt ||
      mode == modePartyBFB || mode == modePartyDFB || mode == modePartyBFT || mode == modePartyDFT || mode == modePartyNukeIn || mode == modePartyNukeOut || mode == modePartySparkle ||
      mode == modePartyRandOn || mode == modePartyRandOff || mode == modePartyLarsonScannerL || mode == modePartyLarsonScannerR || mode == modePartyWaveUp || mode == modePartyWaveDown || mode == modeWait)
      {
        mode = modeDimmingAll;
        Serial.println("All Off");
      }
}

#pragma region standby


bool canEnableStandby() {
  if (standbyActive
    && mode == modeOff)
  {
    return true;
  }
  return false;
}


//standbymode when is dark, and standbyactive
void modeSetStandby() {

  lightSensorRead();

  if (stateLight == false && canEnableStandby())
    mode = modeBrighteningStandby;
  else if (stateLight == true && mode == modeStandby)
    mode = modeOff;
   
}

// first and last two leds on at standbymode
void brighteningStandby() {
  bool changed = false;
  for (int diode = 2; diode < ledCount-2; diode++) {
    outState[diode] = 0;
    if ((outState[0] != standby) || (outState[ledCount-1] != standby)){
      outState[0] = standby;
      outState[ledCount-1] = standby;
      outState[1] = standby/8;
      outState[ledCount-2] = standby/8;
      changed = true;
    }  
  }
   if (!changed) mode = modeStandby;
}

#pragma endregion standby

#pragma region brightening

bool calculateBright(int diode, int step, int maxLvl = brightness){
  if (outState[diode] < maxLvl) {
    int newState = outState[diode] + (int)((double)brightness / step);
    outState[diode] = newState > maxLvl ? maxLvl : newState;
    return true;
  }
  return false;
}


void brighteningAll() {
  bool changed = false;
  for (int diode = 0; diode < ledCount; diode++) {
    changed |= calculateBright(diode, brighteningStepForAll);
  }
  if (!changed) mode = modeOn;
}


void brighteningFromBottom() {
  bool changed = false;
  for (int diode = 0; diode < ledCount; diode++) {   
    changed = calculateBright(diode, brighteningStep);
    if (changed)
      break;
  }
  if (!changed)
    postponeNextMode(modeDimmingFromBottom);
}

void brighteningFromTop() {
  bool changed = false;
  for (int diode = ledCount-1; diode >= 0; diode--) {   
    changed = calculateBright(diode, brighteningStep);
    if (changed)
      break;
  }
  if (!changed)
    postponeNextMode(modeDimmingFromTop);
}

#pragma endregion brightening

#pragma region brighteningALT

void brighteningFromTopAlt() {
  bool changed = false;
  bool revolution = false;
  for (int diode = 1; diode < ledCount; diode++) {   
    if ((outState[diode] < brightness) && (outState[diode-1] > 0)) {
          int newState = outState[diode];
         int beta = map(revolutionSpeed, 4, 16, 8, 1/5); 
        if (revolutionSpeed < 4)
          newState = newState + brighteningAltStep * 18;
          else
           newState = newState + brighteningAltStep * beta;
          if (newState > brightness) newState = brightness;
          outState[diode] = newState;
          newState = outState[diode-1];
           if (revolutionSpeed < 4)
          newState = newState - brighteningAltStep * 18;
          else
           newState = newState - brighteningAltStep * beta;
          if (newState < 0) newState = 0;
          outState[diode-1] = newState;
          changed = true;
          revolution = true;
          break;
    } 
 }  
 if (!revolution) {           //highly experimental code
    if (outState[0] == 0) {
      outState[0] = brightness;
      changed = true;
     revolutionSpeed++;
    }
    else changed = false;
    }
 if (!changed) {
  revolutionSpeed = 0;
  postponeNextMode(modeDimmingFromTopAlt);
 }
}

void brighteningFromBottomAlt() {
  bool changed = false;
  bool revolution = false;
  for (int diode = ledCount-2; diode >= 0; diode--) {   
    if ((outState[diode] < brightness) && (outState[diode+1] > 0)) {
          int newState = outState[diode];
         int beta = map(revolutionSpeed, 4, 16, 8, 1/5); 
        if (revolutionSpeed < 4)
          newState = newState + brighteningAltStep * 18;
          else
           newState = newState + brighteningAltStep * beta;
          if (newState > brightness) newState = brightness;
          outState[diode] = newState;
          newState = outState[diode+1];
        if (revolutionSpeed < 4)
          newState = newState - brighteningAltStep * 18;
          else
           newState = newState - brighteningAltStep * beta;
          if (newState < 0) newState = 0;
          outState[diode+1] = newState;
      changed = true;
      revolution = true;
      break;
    } 
 }  
 if (!revolution) {                         //highly experimental code
    if (outState[ledCount-1] == 0) {
      outState[ledCount-1] = brightness;
      changed = true;
      revolutionSpeed++;
    }
    else changed = false;
    }
 if (!changed) {
  postponeNextMode(modeDimmingFromBottomAlt);
  revolutionSpeed = 0;
 }
}

#pragma endregion brighteningALT

#pragma region dimming

bool calculateDimm(int diode, int step){
  
  if (outState[diode] > 0) {
    int newState = outState[diode] - (int)((double)brightness / step);
    outState[diode] = newState < 0 ? 0 : newState;
    return true;
  }
  return false;
}

void dimmingAll() {
  bool changed = false;
  for (int diode = 0; diode < ledCount; diode++) {
    changed |= calculateDimm(diode, dimmingStepForAll);
  }
  if (!changed)
    mode = modeBrighteningStandby;
}

void dimmingFromBottom() {
  bool changed = false;
  for (int diode = 0; diode < ledCount; diode++) {   
    changed = calculateDimm(diode, dimmingStep);
    if (changed)
      break;
   }
   if (!changed)
    mode = modeBrighteningStandby; 
}

void dimmingFromTop() {
  bool changed = false;
  for (int diode = ledCount-1; diode >= 0; diode--) {
    changed = calculateDimm(diode, dimmingStep);
    if (changed)
      break;
  }
  if (!changed)
    mode = modeBrighteningStandby;
}

#pragma endregion dimming

#pragma region dimmingALT

void dimmingFromTopAlt() {
  bool changed = false;
  bool revolution = false;
  for (int diode = 1; diode < ledCount; diode++) {   
    if ((outState[diode] > 0) && (outState[diode-1] < brightness)) {
          int newState = outState[diode-1];
          newState = newState + dimmingAltStep;
          if (newState > brightness) newState = brightness;
          outState[diode-1] = newState;
          newState = outState[diode];
          newState = newState - dimmingAltStep;
          if (newState < 0) newState = 0;
          outState[diode] = newState;
      changed = true;
      revolution = true;
      break;
    } 
  }  
  if (!revolution) {
      if (outState[0] == brightness) {
      outState[0] = 0;
      changed = true;
    }
      else changed = false;
    }
  
   if (!changed)
    mode =  modeBrighteningStandby;  

}
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

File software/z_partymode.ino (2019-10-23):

int getRandomNoDuplicate(int lower, int upper)  {
  static int offset = 0;
  int randNumber = random(lower, upper);
  if (prevValue == randNumber)
  {
    offset++;
    if (offset >= upper - lower) offset = 1;
    randNumber += offset;
    if (randNumber >= upper) randNumber = lower + randNumber - upper;
  }
  prevValue = randNumber;
  return randNumber;
}

void partyWaveDown() {
  
  bool off = true;
   for (int diode = 0; diode < ledCount; diode++) 
    if (outState[diode] > 0) off = false;
   if (off) {
      for (int diode = 0; diode < ledCount; diode++) {   
      double sinus = (1+sin(11.25 * partyWaveLength*(diode)*PI/180))*brightness/2;
      outState[diode] = (int) sinus;
    }
   }
   
  for (int diode = 0; diode < ledCount; diode++) {   
     int Step = map(partyStep, 1, 2048, 8, 384); 
     Step = constrain(Step, 8, 384); 
     int nState = outState[diode] - Step*mark;
      if (nState <= 0) {
        nState = 0;
        mark = -1;
      } else if (nState > brightness) {
        nState = brightness;
        mark = 1;
      }
      outState[diode] = nState;  
  }
  if (partyloopWave%100 == 0) {
    Serial.print("partyloopWave: ");
    Serial.println(partyloopWave);
  }
  partyloopWave++;
  
 if (partyloopWave > partyloopWaveMax) {
      partyloopWave = 1;
      for (int diode = 0; diode < ledCount; diode++)
      if (outState[diode] > 0) outState[diode] = 0;
      mode = modePartyWaveUp;
  }

}  

void partyWaveUp() {

 bool off = true;
   for (int diode = 0; diode < ledCount; diode++) 
    if (outState[diode] > 0) off = false;
   if (off) {
      for (int diode = 0; diode < ledCount; diode++) {   
      double sinus = (1+sin(11.25 * partyWaveLength*(diode)*PI/180))*brightness/2;
      outState[diode] = (int) sinus;
    }
   }


  for (int diode = ledCount-1; diode >= 0; diode--) {   
      int Step = map(partyStep, 1, 2048, 8, 384);
      Step = constrain(Step, 8, 384);   
      int nState = outState[diode] + Step*mark;
      if (nState <= 0) {
        nState = 0;
        mark = 1;
      }
      else if (nState > brightness) {
        nState = brightness;
        mark = -1;
      }
      outState[diode] = nState;   
  }  
   if (partyloopWave%100 == 0) {
    Serial.print("partyloopWave: ");
    Serial.println(partyloopWave);
   }
  partyloopWave++;
  
 if (partyloopWave > partyloopWaveMax) {
      partyloopWave = 1;
      for (int diode = 0; diode < ledCount; diode++)
      if (outState[diode] > 0) outState[diode] = 0;
      if (!partyTest)
      mode = modePartyLarsonScannerR;
      else
      mode = modeOff;
  }

}

void partyLarsonScannerR() {                        //experimental code, don't know why it works
   bool changed = false;
  bool off = true;
  int newState;
   for (int diode = 0; diode < ledCount; diode++)
    if (outState[diode] > 0) off = false;
   if (off) {
      outState[ledCount-1] = brightness;
      changed = true;
   }
  for (int diode = ledCount-2; diode>0; diode--) {   
    if (outState[diode+1] > 0){
        if (outState[diode+2] > 0) {
      newState = outState[diode+2];
      newState = newState - partyStep;
      if (newState < 0) newState = 0;
      outState[diode+2] = newState;
      }
      if (outState[diode+1] > 0) {
      newState = outState[diode+1];
      newState = newState - partyStep;
      if (newState < 0) newState = 0;
      outState[diode+1] = newState;
      }
      if (outState[diode] < brightness) {
      newState = outState[diode];
      newState = newState + partyStep;
      if (newState > brightness) newState = brightness;
      outState[diode] = newState;
      }
      if (diode>=1){
      newState = outState[diode-1];
      newState = newState + partyStep;
      if (newState > brightness) newState = brightness;
      outState[diode-1] = newState;
      }
      if (diode>=2){
      newState = outState[diode-2];
      newState = newState + partyStep;
      if (newState > brightness) newState = brightness;
      outState[diode-2] = newState;
      }
      if (diode>=3){
      newState = outState[diode-3];
      newState = newState + partyStep;
      if (newState > brightness) newState = brightness;
      outState[diode-3] = newState;
      }
      changed = true;
      break;
    }   
  }
//highly experimental code
   if (partyloopScanner > partyloopScannerMax) {
      partyloopScanner = 1;
      for (int diode = 0; diode < ledCount; diode++)
      if (outState[diode] > 0) outState[diode] = 0;
      if (!partyTest)
      mode = modePartyNukeIn;
      else 
      mode = modeOff;
 
  }
  if (!changed)  {
     partyloopScanner++;  
     mode = modePartyLarsonScannerL;
  }   
}

void partyLarsonScannerL() {                            //experimental code, don't know why it works
   bool changed = false;
   int nState;
  for (int diode = 1; diode < ledCount-1; diode++) {   
    if (outState[diode-1] > 0){
      nState = outState[diode-2];
      nState = nState - partyStep;
      if (nState < 0) nState = 0;
      outState[diode-2] = nState;
      nState = outState[diode-1];
      nState = nState - partyStep;
      if (nState < 0) nState = 0;
      outState[diode-1] = nState;
      nState = outState[diode];
      nState = nState + partyStep;
      if (nState > brightness) nState = brightness;
      outState[diode] = nState;
      if (diode < ledCount-1) {
      nState = outState[diode+1];
      nState = nState + partyStep;
      if (nState > brightness) nState = brightness;
      outState[diode+1] = nState;
      }
      if (diode < ledCount-2) {
      nState = outState[diode+2];
      nState = nState + partyStep;
      if (nState > brightness) nState = brightness;
      outState[diode+2] = nState;
      }
       if (diode < ledCount-3) {
      nState = outState[diode+3];
      nState = nState + partyStep;
      if (nState > brightness) nState = brightness;
      outState[diode+3] = nState;
      }
      changed = true;
      break;
    }   
  }
  if (!changed) mode = modePartyLarsonScannerR;  
}

void partyNukeIn() {
  bool changed = false;
  for (int diode = 0; diode < ledCount; diode++) {   
    if (outState[diode] < brightness) {
      int newState = outState[diode];
      double sinus = sin(11*(diode+1)*PI/180)*partyStep/2;
     
      int Step = (int) sinus+3 ;
      newState = newState + Step;
      if (newState > brightness) newState = brightness;
      outState[diode] = newState;
      changed = true;
    }
  }
  if (partyloopNuke > partyloopNukeMax) {           //highly experimental code
      partyloopNuke = 1;
      for (int diode = 0; diode < ledCount; diode++)
      if (outState[diode] > 0) outState[diode] = 0;
      if (!partyTest)
      mode = modePartySparkle;
      else
      mode = modeOff;
  }
   if (!changed)  {
     partyloopNuke++;  
     mode = modePartyNukeOut;
  } 
   
}
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

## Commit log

2019-10-23 initial code
    [schody.v1.brd, schody.v1.sch, schody.v2.brd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]
2019-10-23 pleban ver. 19 stairs, 2 relays
    [schody.v2.brd, schody.v2.sch]

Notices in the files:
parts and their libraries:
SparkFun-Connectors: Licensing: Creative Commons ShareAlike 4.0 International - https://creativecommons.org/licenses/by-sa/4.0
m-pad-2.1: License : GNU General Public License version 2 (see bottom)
